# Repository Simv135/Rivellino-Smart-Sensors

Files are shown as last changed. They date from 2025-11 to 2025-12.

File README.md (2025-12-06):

# Rivellino Smart Sensors

## Introduzione

Il sistema **Rivellino Smart Sensors** è progettato per monitorare le condizioni ambientali all'interno del ***Rivellino degli Invalidi***, parte del **Museo Pietro Micca** di Torino.  
I sensori installati nei tre moduli principali **Tirante (A)**, **Galleria (B)** e **Polveriera (C)** raccolgono dati su:

- Temperatura e Umidità  
- Qualità dell’aria (CO e NO₂)  
- Vibrazioni
- Allagamento

Questi dati vengono trasmessi via seriale ad un Raspberry Pi e letti da un ricevitore scritto in Python, che li elabora e li salva automaticamente in file CSV.  
Il sistema garantisce un monitoraggio continuo e affidabile degli ambienti ipogei, contribuendo alla **tutela e alla conservazione del patrimonio storico**.

## I moduli
- [Modulo Ricevitore](#Il-ricevitore) per l'elaborazione dei dati
- [Modulo A](#Modulo-A) → tirante (Temperatura e Umidità, Aria, Vibrazioni)
- [Modulo B](#Modulo-B) → galleria (Batterie, Temperatura e Umidità, Aria, Allagamento)
- [Modulo C](#Modulo-C) → polveriera (Batterie, Temperatura e Umidità)

diagramma_funzionale

<br><br>

## I dati

| ID | Descrizione | Valore | Modulo  |
|---|---|---|---|
| a | Batteria | % | B |
| b | Batteria | % | C |
| c | Temperatura | °C | A |
| d | Temperatura | °C | B |
| e | Temperatura | °C | C |
| f | Umidità | % | A |
| g | Umidità | % | B |
| h | Umidità | % | C |
| i | Aria (CO) | ppm | A |
| j | Aria (NO2) | ppm | B |
| k | Vibrazioni | Hz | A |
| l | Vibrazioni | m/s² | A |
| m | Allagamento | 0 / 1 | B |

I dati verranno elaborati dal ricevitore e salvati all'interno dei files CSV.

<br><br>

## Posizionamento

Mappa_Rivellino

<br><br>

## Disegno Meccanico

| | |
|:---:|:---:|
| ModuloA | ModuloB |
| [ModuloA](disegno_meccanico/moduloA/Case_Tirante.stl) | [ModuloB e ModuloC](disegno_meccanico/moduloB/Case_Galleria.stl) |
| ModuloA_Condotto | Coperchio |
| [Condotto Aria (ModuloA)](disegno_meccanico/moduloA/Condotto_Aria.stl) | [Coperchio (ModuloA, ModuloB e Modulo C)](disegno_meccanico/moduloA/Coperchio.stl) |

<br><br>

## Il ricevitore

Assicurarsi di avere l'ultima versione di Python3 installata sul dispositivo (in questo caso sul Raspberry Pi 5).

Eseguire ```pip install pyserial``` nel terminale per installare la libreria pyserial.

Eseguire ```python3 main.py``` nel terminale, all'interno della cartella in cui si trova il programma ricevitore.

Il programma proverà a connettersi alla porta seriale. Quando la connessione sarà stabilita verrà mostrata la porta utilizzata e la velocità di comunicazione impostata.

Il programma riceverà dati periodicamente. Esempio di dati inviati da parte dei moduli:
- moduloA:    `c28f58j0.06k15.5l1.9i0.07`
- moduloB:    `a61d27g56m1`
- moduloC:    `b62e28h42`

I dati verranno salvati nella cartella DatiSensori nei seguenti files:

| File CSV | ID del dato |
|---|---|
| allagamento.csv | m |
| ariaCO.csv | i |
| ariaNO2.csv | j |
| batterie.csv | a, b |
| vibrazioni.csv | k, l |
| temperatura_umidita.csv | c, d, e, f, g, h |

Il file di configurazione `config.py` permette di modificare alcuni parametri relativi al programma di ricezione dei dati, tra cui:
- Selezionare la porta di comunicazione
- Selezionare la velocità di comunicazione (baud rate)
- Selezionare il percorso dei files CSV
- Rinominare i files CSV e di inserirne di nuovi
- Mappare nuovi sensori
- Modificare le colonne dei files CSV
- Scegliere se mostrare i dati ricevuti sul terminale
- Personalizzare i messaggi di log

Le informazioni di comunicazione ed eventuali errori saranno salvati all'interno di: `logfile.log`

## Librerie Arduino
Estrarre `libraries.zip` all'interno della cartella `C:\Users\%USERPROFILE%\Documents\Arduino\`, riavviare eventualmente Arduino IDE.

## Configurazione LoRa
- Lora Modulo A
  - `AT+ADDRESS=1`
  - `AT+NETWORKID=5`
  - `AT+IPR=9600`
- Lora Modulo B
  - `AT+ADDRESS=2`
  - `AT+NETWORKID=5`
  - `AT+IPR=9600`
- Lora Modulo C
  - `AT+ADDRESS=3`
  - `AT+NETWORKID=5`
  - `AT+IPR=9600`

## Modulo A

ModuloA

<br><br>

**Componenti**:
- Arduino Nano 33 BLE Sense Rev2
- Sensore Qualità Aria Mikroe3056
- Modulo LoRa RYLR498

Esempio di dati inviati:
`c28f58j0.06k15.5l1.9i0.07`

| ID | Descrizione | Valore |
|---|---|---|
| c | Temperatura | °C |
| f | Umidità | % |
| i | Aria (CO) | ppm |
| j | Aria (NO2) | ppm |
| k | Vibrazioni | Hz |
| l | Vibrazioni | m/s² |

<br><br>

## Modulo B

ModuloB

<br><br>

**Componenti**:
- Arduino Pro Mini
- Sensore Temperatura e Umidità DHT11
- Sensore Allagamento HW-038
- Modulo LoRa RYLR498
- Batterie AA Alcaline x5 (serie)

Esempio di dati inviati:
`a61d27g56m1`

| ID | Descrizione | Valore |
|---|---|---|
| a | Batteria | % |
| d | Temperatura | °C |
| g | Umidità | % |
| m | Allagamento | 0 / 1 |

<br><br>

## Modulo C

ModuloC

<br><br>

**Componenti**:
- Arduino Pro Mini
- Sensore Temperatura e Umidità DHT11
- Modulo LoRa RYLR498
- Batterie AA Alcaline x5 (serie)

Esempio di dati inviati:
`b62e28h42`

| ID | Descrizione | Valore |
|---|---|---|
| b | Batteria | % |
| e | Temperatura | °C |
| h | Umidità | % |

<br><br>

***ITS AEROSPAZIO PIEMONTE***

***CORSO EMBT02***

***Rivellino Smart Sensors***

<br><br>

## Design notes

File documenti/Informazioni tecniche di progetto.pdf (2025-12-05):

# Rivellino Smart Sensors

## Introduzione

Il sistema Rivellino Smart Sensors è progettato per monitorare le condizioni ambientali all'interno del Rivellino degli Invalidi, parte del Museo Pietro Micca di Torino.
I sensori installati nei tre moduli principali Tirante (A), Galleria (B) e Polveriera (C) raccolgono dati su:
- Temperatura e Umidità
- Qualità dell’aria (CO e NO₂)
- Vibrazioni
- Allagamento

Questi dati vengono trasmessi via seriale ad un Raspberry Pi e letti da un ricevitore scritto in Python, che li elabora e li salva automaticamente in file CSV.
Il sistema garantisce un monitoraggio continuo e affidabile degli ambienti ipogei, contribuendo alla tutela e alla conservazione del patrimonio storico.

## I moduli

- Modulo Ricevitore per l'elaborazione dei dati
- Modulo A → tirante (Temperatura e Umidità, Aria, Vibrazioni)
- Modulo B → galleria (Batterie, Temperatura e Umidità, Aria, Allagamento)
- Modulo C → polveriera (Batterie, Temperatura e Umidità)

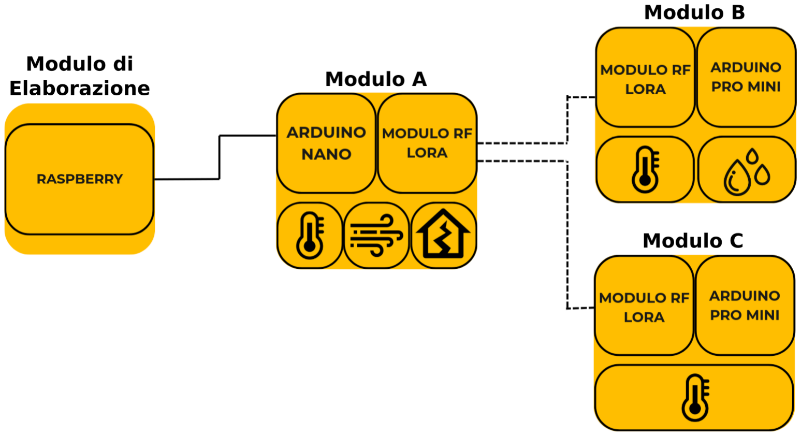
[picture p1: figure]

## I dati

ID | Descrizione | Valore | Modulo
a | Batteria | % | B
b | Batteria | % | C
c | Temperatura | °C | A
d | Temperatura | °C | B
e | Temperatura | °C | C
f | Umidità | % | A
g | Umidità | % | B
h | Umidità | % | C
i | Aria (CO) | ppm | A
j | Aria (NO2) | ppm | B
k | Vibrazioni | Hz | A
l | Vibrazioni | m/s² | A
m | Allagamento | 0 / 1 | B

I dati verranno elaborati dal ricevitore e salvati all'interno dei files CSV.

## Posizionamento

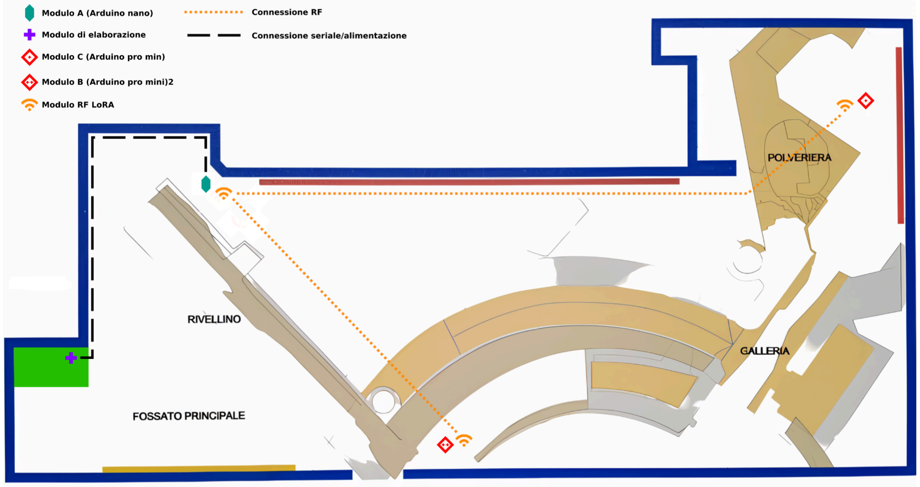
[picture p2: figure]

## Il ricevitore

Assicurarsi di avere l'ultima versione di Python3 installata sul dispositivo (in questo caso sul Raspberry Pi 5).

Eseguire pip install pyserial nel terminale per installare la libreria pyserial.

Eseguire python3 main.py nel terminale, all'interno della cartella in cui si trova il programma ricevitore.

Il programma proverà a connettersi alla porta seriale. Quando la connessione sarà stabilita verrà mostrata la porta utilizzata e la velocità di comunicazione impostata.

Il programma riceverà dati periodicamente. Esempio di dati inviati da parte dei moduli:

- moduloA: c28f58j0.06k15.5l1.9i0.07
- moduloB: a61d27g56m1
- moduloC: b62e28h42

I dati verranno salvati nella cartella “DatiSensori” nei seguenti files:

File CSV | ID del dato
allagamento.csv | m
ariaCO.csv | i
ariaNO2.csv | j
batterie.csv | a, b
vibrazioni.csv | k, l
temperatura_umidita.csv | c, d, e, f, g, h

Il file di configurazione config.py permette di modificare alcuni parametri relativi al programma di ricezione dei dati, tra cui:

- Selezionare la porta di comunicazione
- Selezionare la velocità di comunicazione (baud rate)
- Selezionare il percorso dei files CSV
- Rinominare i files CSV e di inserirne di nuovi

- Mappare nuovi sensori
- Modificare le colonne dei files CSV
- Scegliere se mostrare i dati ricevuti sul terminale
- Personalizzare i messaggi di log

Le informazioni di comunicazione ed eventuali errori saranno salvati all'interno di: logfile.log

## Librerie Arduino

Estrarre libraries.zip all'interno della cartella C:\Users\%USERPROFILE%\Documents\Arduino\, riavviare eventualmente Arduino IDE.

## Configurazione LoRa

- Lora Modulo A
- AT+ADDRESS=1
- AT+NETWORKID=5
- AT+IPR=9600
- Lora Modulo B
- AT+ADDRESS=2
- AT+NETWORKID=5
- AT+IPR=9600
- Lora Modulo C
- AT+ADDRESS=3
- AT+NETWORKID=5
- AT+IPR=9600

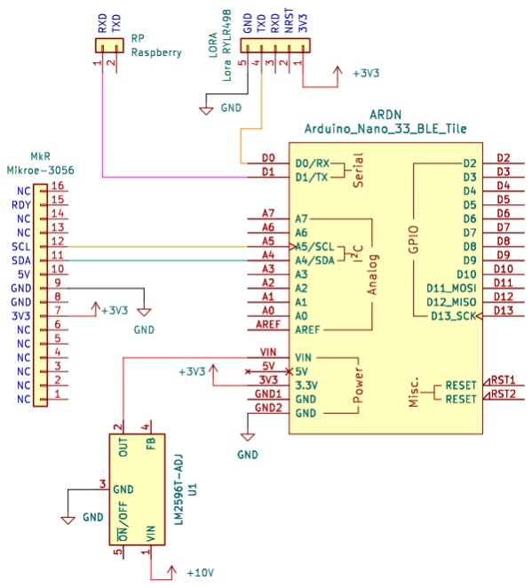
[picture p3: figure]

## Modulo A

Componenti:

- Arduino Nano 33 BLE Sense Rev2
- Sensore Qualità Aria Mikroe3056
- Modulo LoRa RYLR498

Esempio di dati inviati:
c28f58j0.06k15.5l1.9i0.07

ID | Descrizione | Valore
c | Temperatura | °C
f | Umidità | %
i | Aria (CO) | ppm
j | Aria (NO2) | ppm
k | Vibrazioni | Hz
l | Vibrazioni | m/s²

## Modulo B

Componenti:

- Arduino Pro Mini
- Sensore Temp. e Umidità DHT11
- Sensore Allagamento HW-038
- Modulo LoRa RYLR498
- Batterie AA Alcaline x5 (serie)

Esempio di dati inviati: a61d27g56m1

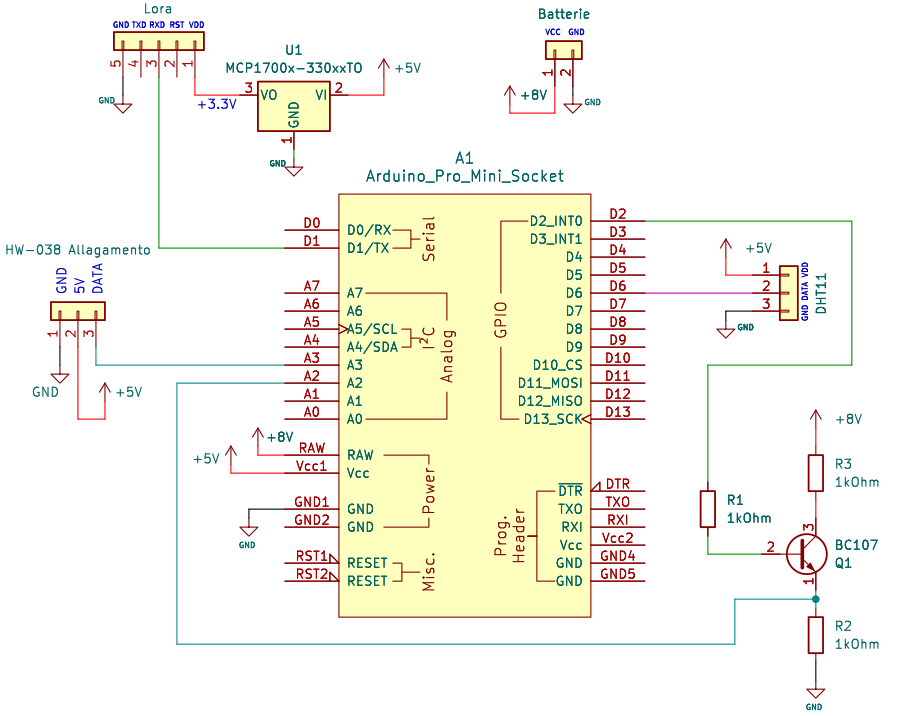
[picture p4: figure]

ID | Descrizione | Valore
a | Batteria | %
d | Temperatura | °C
g | Umidità | %
m | Allagamento | 0 / 1

## Modulo C

Componenti:

- Arduino Pro Mini
- Sensore Temp. e Umidità DHT11
- Modulo LoRa RYLR498
- Batterie AA Alcaline x5 (serie)

Esempio di dati inviati: b62e28h42

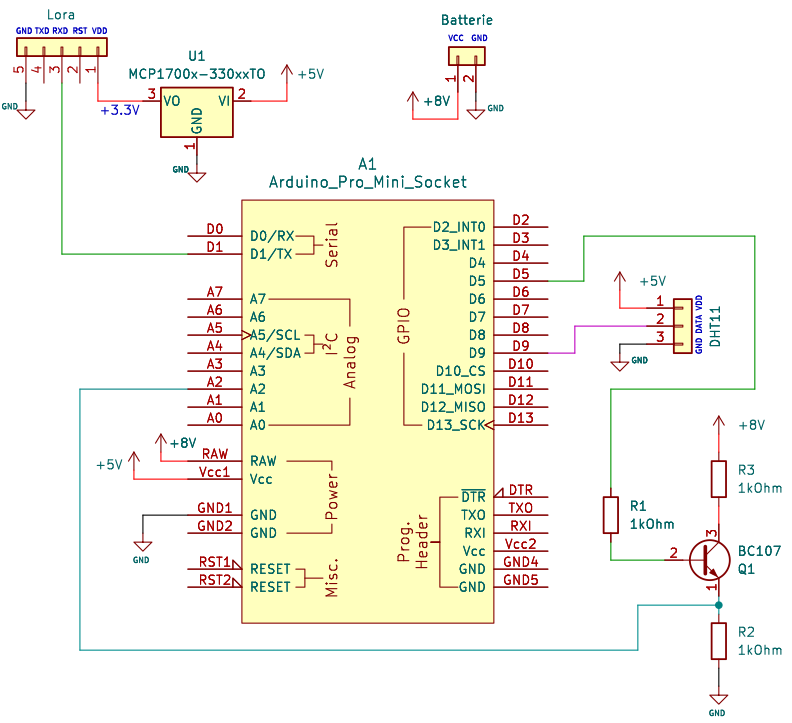
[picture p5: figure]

ID | Descrizione | Valore
b | Batteria | %
e | Temperatura | °C
h | Umidità | %

ITS AEROSPAZIO PIEMONTE
CORSO EMBT02
Rivellino Smart Sensors | https://github.com/Simv135/Rivellino-Smart-Sensors

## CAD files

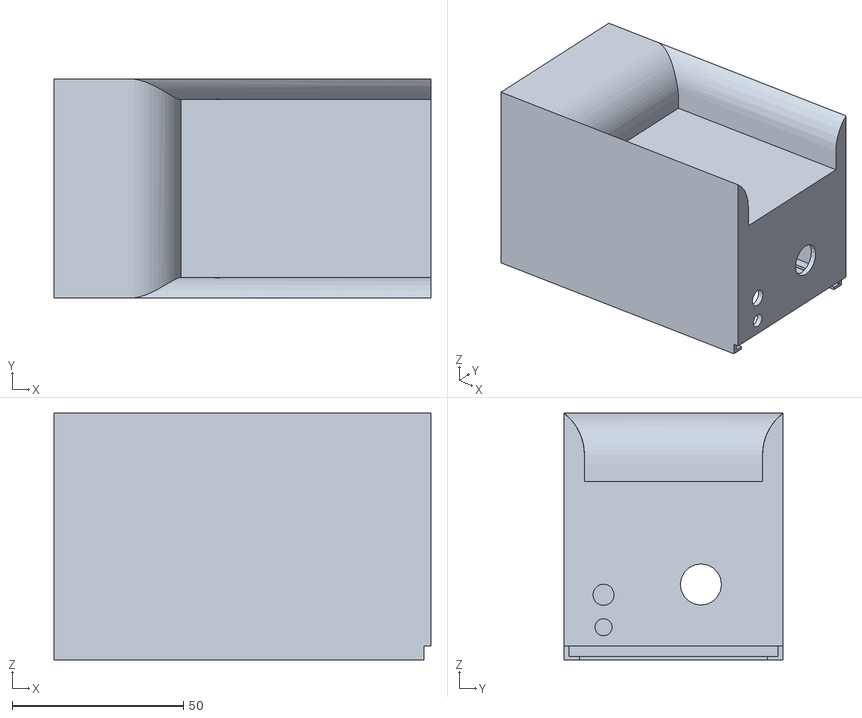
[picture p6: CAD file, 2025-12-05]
disegno_meccanico/moduloA/Case_Tirante.stl
110.0 x 64.0 x 72.0

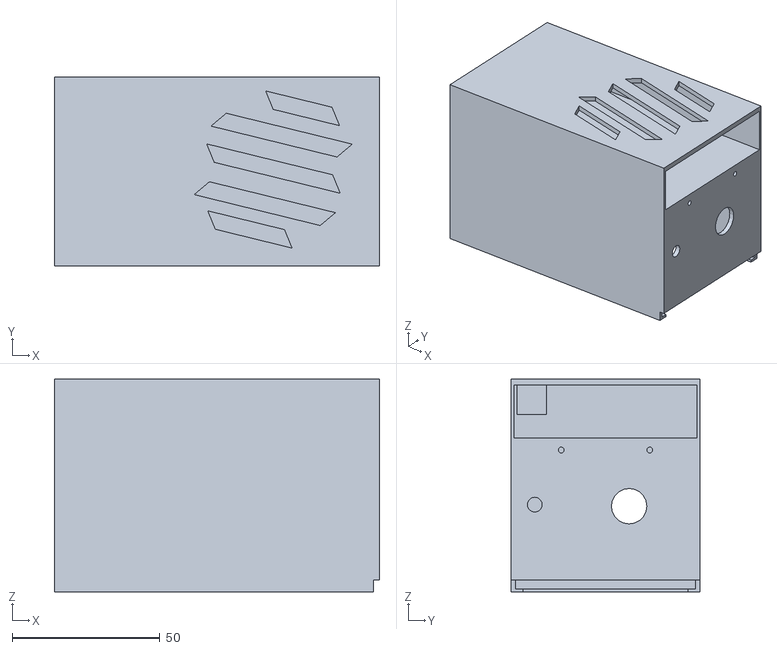
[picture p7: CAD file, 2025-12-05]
disegno_meccanico/moduloB/Case_Galleria.stl
110.0 x 64.0 x 72.0

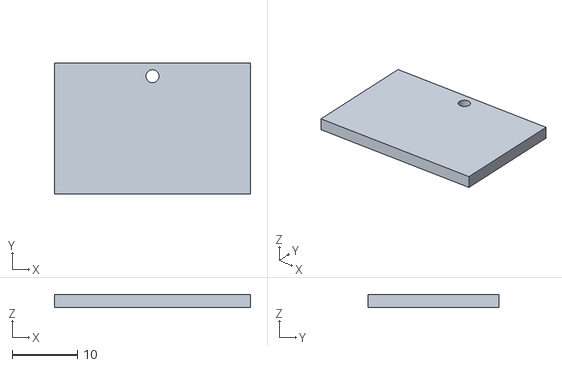
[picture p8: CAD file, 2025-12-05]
disegno_meccanico/moduloC/Vano_Batteria.stl
30.0 x 20.0 x 2.00

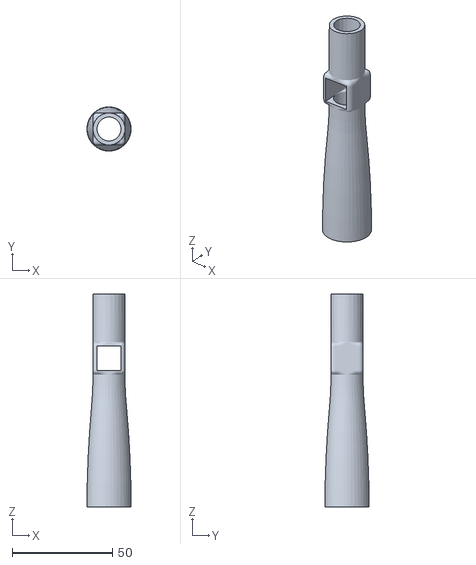
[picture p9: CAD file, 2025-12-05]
disegno_meccanico/moduloA/Condotto_Aria.stl
22.0 x 22.0 x 106.0

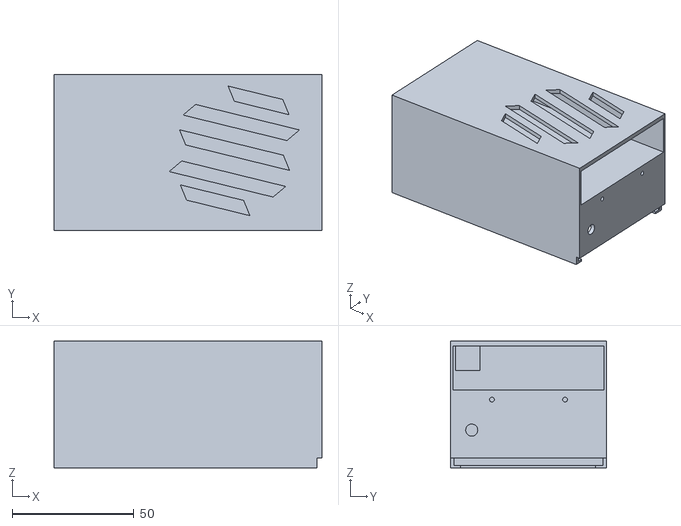
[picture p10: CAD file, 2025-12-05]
disegno_meccanico/moduloC/Case_Polveriera.stl
110.0 x 64.0 x 52.0

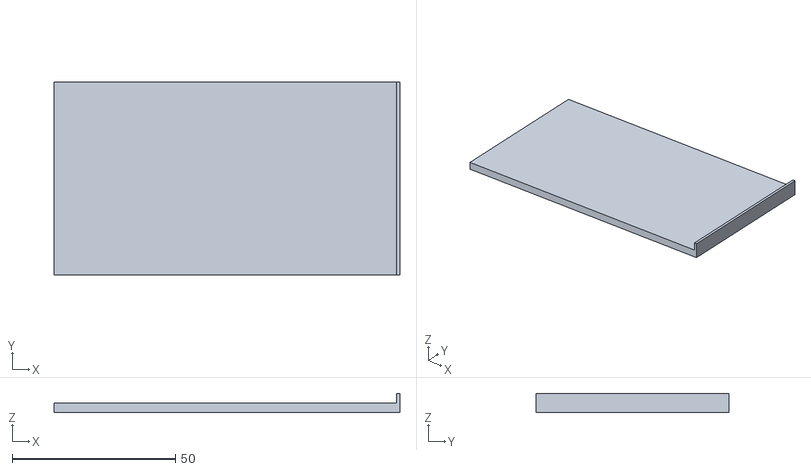
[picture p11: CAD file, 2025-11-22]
disegno_meccanico/moduloA/Coperchio.stl
106.0 x 59.0 x 5.90

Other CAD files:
disegno_meccanico/moduloA/Case_Tirante.prt
disegno_meccanico/moduloA/Condotto_Aria.prt
disegno_meccanico/moduloA/Coperchio.prt
disegno_meccanico/moduloB/Case_Galleria.prt
disegno_meccanico/moduloB/Coperchio.prt
disegno_meccanico/moduloB/Vano_Batteria.prt
disegno_meccanico/moduloC/Case_Polveriera.prt
disegno_meccanico/moduloC/Coperchio.prt
disegno_meccanico/moduloC/Vano_Batteria.prt

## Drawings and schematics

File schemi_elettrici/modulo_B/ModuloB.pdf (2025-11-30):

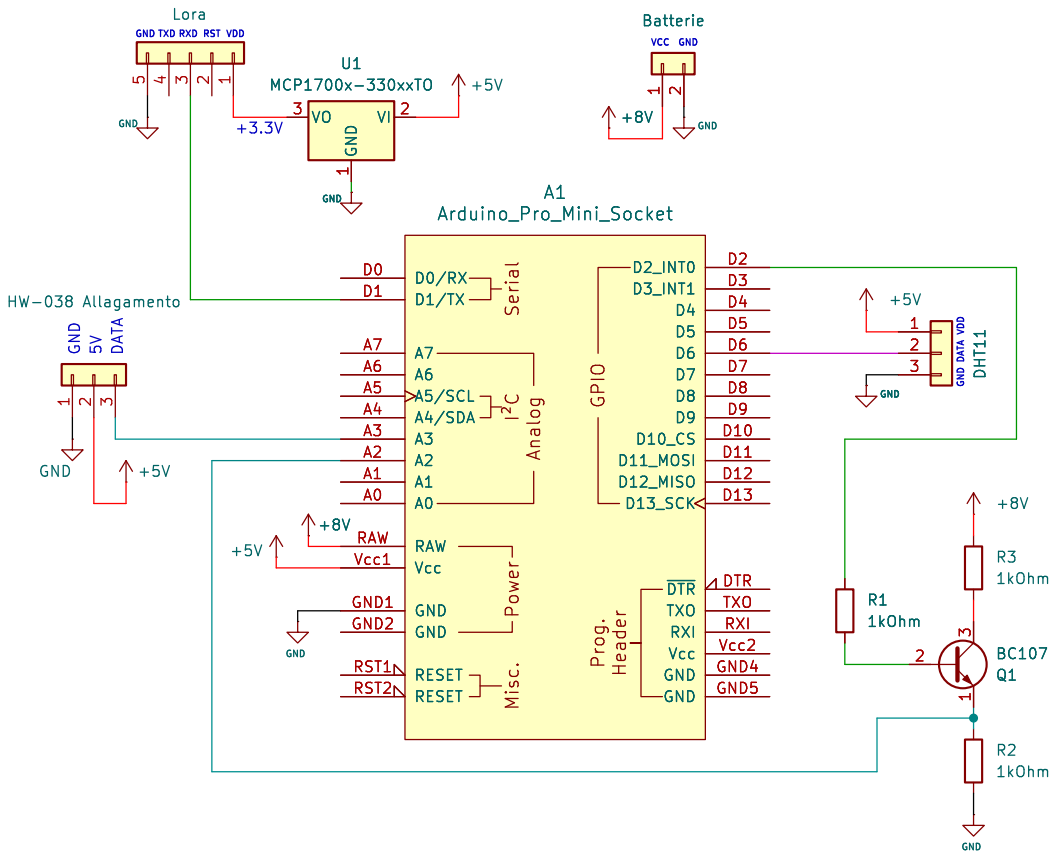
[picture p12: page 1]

3 1 A1 Arduino_Pro_Mini_Socket D0/RX D0 D1/TX D1 A7 A7 A6 A6 A5/SCL A5 A4/SDA A4 A3 A3 A2 A2 A1 A1 A0 A0 RAW RAW

3 HW-038 Allagamento Serial þÿI²C Power Misc. AnalogGPIO Prog. Header D0/RX D0 D1/TX D1 A7 A7 A6 A6 A5/SCL A5 A4/SDA A4 A3 A3 A2 A2 A1 A1 A0 A0 RAW RAW

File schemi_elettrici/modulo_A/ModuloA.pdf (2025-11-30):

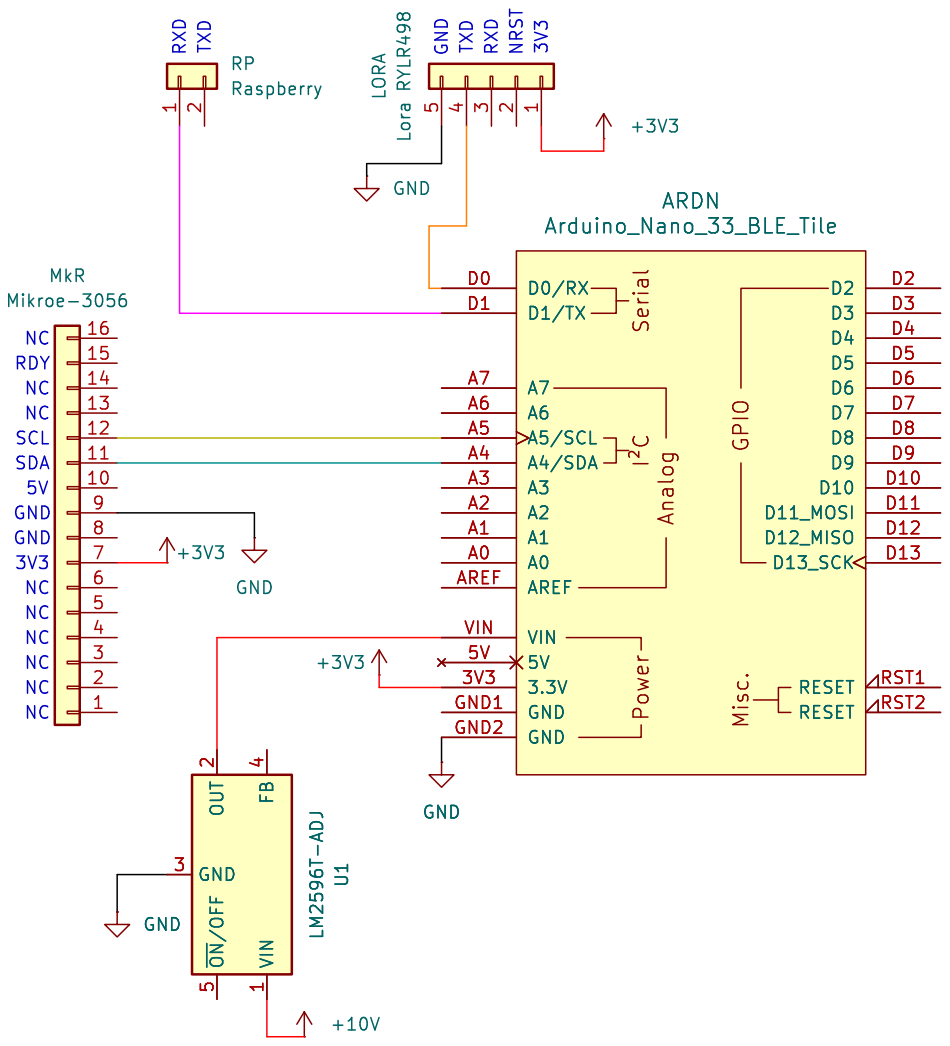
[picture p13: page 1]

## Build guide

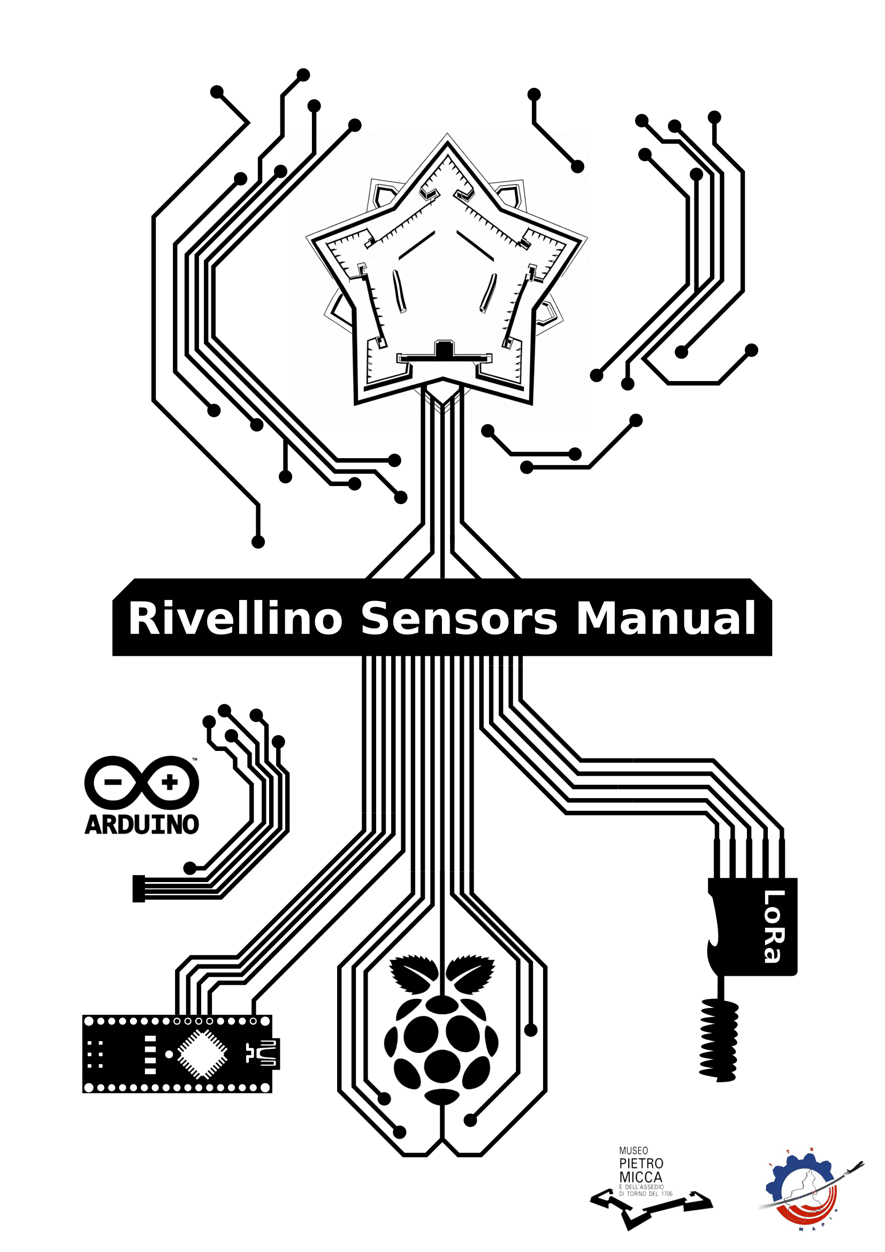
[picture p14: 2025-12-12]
documenti/documenti_editabili_e_immagini/riivellino_manual_first_page_Gabriele_Barletta_EMBT02.png

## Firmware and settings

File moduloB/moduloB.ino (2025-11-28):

//Estrarre "libraries.zip" all'interno della cartella "C:\Users\%USERPROFILE%\Documents\Arduino\", riavviare eventualmente Arduino IDE
//impostare usb to ttl con vdd a 5V
//collegare VDD e GND
//collegare tx(usb to ttl) con rx(Arduino) ed rx(usb to ttl) con tx(Arduino)
//premere il pulsante di reset subito dopo la compilazione del codice per caricare il codice sul Pro Mini e non collegare il pin di reset
//Per info: https://github.com/Simv135/Rivellino-Smart-Sensors

// --- LIBRERIE ---
#include <Wire.h>
#include "DHT.h"
#include <avr/sleep.h>
#include <avr/power.h>
#include <avr/wdt.h>

// --- CONFIGURAZIONI ---
#define WDT_INTERVAL          8     // Ogni ciclo WDT è 8s
#define TEMP_HUM_CYCLES       4     // Leggi ogni 32s
#define WATER_CYCLES          1     // Leggi ogni 8s
#define WATER_THRESHOLD       10    // Soglia allagamento

// --- PIN ---
#define DHT11_DATA_PIN        6
#define HW038_DATA_PIN        A3
#define BATTERY_READ_EN       2
#define BATTERY_READ_PIN      A2
#define LED_BATTERY           11  //da completare il circuito con il LED nel circuito

DHT dht11(DHT11_DATA_PIN, DHT11);

// --- VARIABILI SENSORI ---
float temp, hum;
unsigned short voltage;
byte battery;
bool all;

// --- VARIABILI TIMER ---
volatile byte temp_hum_counter = 0;
volatile byte water_counter = 0;
volatile bool time_to_read_temp_hum = false;
volatile bool time_to_read_water = false;

// --- SETUP ---
void setup() {
  Serial.begin(9600);
  while (!Serial);

  pinMode(BATTERY_READ_EN,OUTPUT);

  dht11.begin();

  setupWatchdog();

  powerStateLed();  //visualizza stato della batteria partendo dal LED
  //Implementare un pulsante di reset per visualizzare lo stato della batteria manualmente
}

// --- LOOP PRINCIPALE ---
void loop() {
  sleepUntilNextReading();

  if (time_to_read_temp_hum) {
    readTempHum();
    readBattery();
    sendData(
      "d" + String(temp) + 
      "g" + String(hum) + 
      "m" + String(all) + 
      "a" + String(battery)
    );
    time_to_read_temp_hum = false;
  }

  if (time_to_read_water) {
    readWater();
    if (all=1){
      sendData("m" + String(all));
    }
    time_to_read_water = false;
  }
}

// --- INVIO DATI ---
void sendData(String data) {
  Serial.println("AT+MODE=0"); //sleep off
  delay(500);

  Serial.print("AT+SEND=1,");
  Serial.print(data.length());
  Serial.print(",");
  Serial.println(data);

  delay(1000);
  Serial.println("AT+MODE=1"); //sleep on
}

// --- LETTURA TEMPERATURA / UMIDITÀ ---
void readTempHum() {
  temp = dht11.readTemperature();
  hum = dht11.readHumidity();
}

// --- LETTURA ALLAGAMENTO ---
void readWater() {
  int count = 0;
  for (byte i = 0; i < 5; i++) {
    count += (analogRead(HW038_DATA_PIN) >= WATER_THRESHOLD);
    delay(5);
  }

  all = (count >= 3);
}

// --- LETTURA BATTERIA ---
void readBattery() {
  digitalWrite(BATTERY_READ_EN,HIGH);
  delay(1000);
  voltage = analogRead(BATTERY_READ_PIN);
  digitalWrite(BATTERY_READ_EN,LOW);

  //da calcolare meglio le soglie in base al partitore di tensione nel circuito
  //                   ^
  //                   |
  if      (voltage < 4600) battery = 0;
  else if (voltage < 4850) battery = 20;
  else if (voltage < 4950) battery = 40;
  else if (voltage < 5000) battery = 60;
  else if (voltage < 5025) battery = 80;
  else                     battery = 100;
}

// --- LED BATTERIA ---
//Indicatore LED per lo stato della batteria
void powerStateLed(){ 
  readBattery();
  if (battery==0){
    digitalWrite(LED_BATTERY, HIGH);
    delay(500);
    digitalWrite(LED_BATTERY, LOW);
  }else if (battery<=20){
    digitalWrite(LED_BATTERY, HIGH);
    delay(500);
    digitalWrite(LED_BATTERY, LOW);
    delay(500);
    digitalWrite(LED_BATTERY, HIGH);
    delay(500);
    digitalWrite(LED_BATTERY, LOW);
  }else if (battery<=40){
    digitalWrite(LED_BATTERY, HIGH);
    delay(1000);
    digitalWrite(LED_BATTERY, LOW);
  }else if (battery<=60){
    digitalWrite(LED_BATTERY, HIGH);
    delay(1000);
    digitalWrite(LED_BATTERY, LOW);
    delay(1000);
    digitalWrite(LED_BATTERY, HIGH);
    delay(1000);
    digitalWrite(LED_BATTERY, LOW);
  }else if (battery<=80){
    digitalWrite(LED_BATTERY, HIGH);
    delay(2000);
    digitalWrite(LED_BATTERY, LOW);
  }else if (battery<=100){
    digitalWrite(LED_BATTERY, HIGH);
    delay(2000);
    digitalWrite(LED_BATTERY, LOW);
    delay(2000);
    digitalWrite(LED_BATTERY, HIGH);
    delay(2000);
    digitalWrite(LED_BATTERY, LOW);
  }
}

// --- WATCHDOG ---
void setupWatchdog() {
  cli();
  wdt_reset();
  MCUSR &= ~(1 << WDRF);
  WDTCSR |= (1 << WDCE) | (1 << WDE);
  WDTCSR = (1 << WDIE) | (1 << WDP3) | (0 << WDP2) | (0 << WDP1) | (1 << WDP0); // 8s
  sei();
}

ISR(WDT_vect) {
  temp_hum_counter++;
  water_counter++;

  if (water_counter >= WATER_CYCLES) {
    time_to_read_water = true;
    water_counter = 0;
  }

  if (temp_hum_counter >= TEMP_HUM_CYCLES) {
    time_to_read_temp_hum = true;
    temp_hum_counter = 0;
  }
}

// --- SLEEP ---
void sleepUntilNextReading() {
  ADCSRA &= ~(1 << ADEN);
  set_sleep_mode(SLEEP_MODE_PWR_DOWN);
  do {
    sleep_enable();
    sleep_mode();
    sleep_disable();
  } while (!time_to_read_temp_hum && !time_to_read_water);
  ADCSRA |= (1 << ADEN);
}
  

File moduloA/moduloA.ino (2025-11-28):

//Estrarre "libraries.zip" all'interno della cartella "C:\Users\%USERPROFILE%\Documents\Arduino\", riavviare eventualmente Arduino IDE
//Per info: https://github.com/Simv135/Rivellino-Smart-Sensors

// --- LIBRERIE ---
#include "Arduino_BMI270_BMM150.h"
#include <Arduino_HS300x.h>
#include <math.h>  // Per fabs() e isnan()

// Librerie sensore aria
#include <Wire.h>
#include <Adafruit_ADS1X15.h>

// Creazione dell'istanza dell'ADS1115
Adafruit_ADS1X15 ads;

// Costanti di configurazione
#define VIBRATION_THRESHOLD 0.03            // Soglia variazione accelerazione per stampare
#define VIBRATION_MIN_INTERVAL 50           // Minimo tempo tra rilevazioni valide (ms)
#define ENV_INTERVAL 5000                   // Intervallo lettura temperatura/umidità e aria (ms)

// Variabili aria
float R0_CO = 10.0;   // Resistenze in aria pulita
float R0_NO2 = 20.0;  
int16_t co_raw; // tensioni dai canali ADC
int16_t no2_raw;
float co_voltage; // valori raw in tensione (V)
float no2_voltage;
float R_s_CO; // resistenza del sensore (R_s)
float R_s_NO2;
float ppm_CO; // concentrazioni in ppm
float ppm_NO2;

// Variabili vibrazione
float x, y, z;
float vibration = 0.0;
float lastVibration = 0.0;
float lastPrintedVibration = 0.0;
float lastPrintedFrequency = 0.0;
bool firstRead = true;

// Variabili frequenza
unsigned long lastTime = 0;
unsigned long currentTime = 0;
unsigned long deltaTime = 0;
float frequencyVibration = 0.0;

// Variabili messaggi
String rawData, message;
int firstComma, secondComma, thirdComma;

// Timer temperatura/umidità
unsigned long lastEnvRead = 0;
unsigned long currentMillis = 0;

void setup() {
  Serial1.begin(9600);
  while (!Serial1);
  Serial.begin(9600);
  while (!Serial);

  ads.begin();

  if (!IMU.begin()) {
    Serial1.println("[A] Errore inizializzazione IMU!");
    Serial.println("[A] Errore inizializzazione IMU!");
    while (1);
  }

  if (!HS300x.begin()) {
    Serial1.println("[A] Errore inizializzazione sensore HS300x!");
    Serial.println("[A] Errore inizializzazione sensore HS300x!");
    while (1);
  }
}

void loop() {
  currentMillis = millis();

  if (readAccelerometer()) {
    // Filtro per stampare solo se:
    // - la vibrazione è cambiata significativamente
    // - la frequenza è cambiata abbastanza da evitare ripetizioni inutili
    if (fabs(vibration - lastPrintedVibration) >= VIBRATION_THRESHOLD &&
        fabs(frequencyVibration - lastPrintedFrequency) >= 0.5 &&
        deltaTime != VIBRATION_MIN_INTERVAL &&
        frequencyVibration > 0.0 && frequencyVibration < 100.0)
    {
      printVibrationData();
      lastPrintedVibration = vibration;
      lastPrintedFrequency = frequencyVibration;
    }
  }

  if (currentMillis - lastEnvRead >= ENV_INTERVAL) {
    lastEnvRead = currentMillis;
    printAirData();
    printTempHumData();
  }

  receiveData();
}

void receiveData() {

  if (Serial1.available()) {
    rawData = Serial1.readStringUntil('\n');  // Legge fino a newline

    if (rawData.startsWith("+RCV=")) {
      firstComma = rawData.indexOf(',');
      secondComma = rawData.indexOf(',', firstComma + 1);
      thirdComma = rawData.indexOf(',', secondComma + 1);

      if (firstComma > 0 && secondComma > 0 && thirdComma > 0) {
        message = rawData.substring(secondComma + 1, thirdComma);
        Serial1.println(message);
        Serial.println(message);
      }
    }
  }
}

// Funzione per lettura accelerometro e calcolo frequenza
bool readAccelerometer() {
  if (IMU.accelerationAvailable()) {
    IMU.readAcceleration(x, y, z);
    vibration = sqrt(x * x + y * y + z * z);  // Magnitudo accelerazione

    if (firstRead || fabs(vibration - lastVibration) >= VIBRATION_THRESHOLD) {
      currentTime = millis();
      deltaTime = currentTime - lastTime;

      if (!firstRead && deltaTime >= VIBRATION_MIN_INTERVAL) {
        frequencyVibration = 1000.0 / deltaTime;
      }

      lastTime = currentTime;
      lastVibration = vibration;
      firstRead = false;
    }
  }

  return (!isnan(vibration) && frequencyVibration > 0.0 && frequencyVibration < 100.0);
}

void readAirQuality(){
  co_raw = ads.readADC_SingleEnded(0);
  no2_raw = ads.readADC_SingleEnded(1);
  
  // Conversione dei valori raw in tensione (V)
  co_voltage = co_raw * 6.144 / 32768.0;
  no2_voltage = no2_raw * 6.144 / 32768.0;
  
  // Calcolo della resistenza del sensore (R_s)
  R_s_CO = (5.0 - co_voltage) / co_voltage * R0_CO;
  R_s_NO2 = (5.0 - no2_voltage) / no2_voltage * R0_NO2;
  
  // Calcolo delle concentrazioni in ppm usando curve empiriche dal datasheet
  ppm_CO = pow((R_s_CO / R0_CO), -1.179) * 4.385;   // Formula per CO
  ppm_NO2 = pow((R_s_NO2 / R0_NO2), 1.007) * 6.855; // Formula per NO2
}

// Stampa dati aria
void printAirData() {
  readAirQuality();
  Serial.print("i");  // Aria CO
  Serial.print(ppm_CO);
  Serial.print("j");  // Aria NO2
  Serial.println(ppm_NO2);
}

// Stampa dati vibrazione
void printVibrationData() {
  Serial.print("k");  // Frequenza (Hz)
  Serial.print(frequencyVibration, 2);
  Serial.print("l");  // Intensità vibrazione (m/s²)
  Serial.println(vibration, 2);
}

// Stampa temperatura e umidità
void printTempHumData() {
  Serial.print("c");  // Temperatura
  Serial.print(HS300x.readTemperature());
  Serial.print("f");  // Umidità
  Serial.println(HS300x.readHumidity());
}

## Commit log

2025-05-19 Update moduloB.ino
    Correzione dell'errore migliorata
    [moduloB.ino]
2025-05-19 Update moduloC.ino
    correzione gestione errore batterie
    [moduloC.ino]
2025-11-28 Librerie Arduino (estrarre la zip e inserire le librerie in Documenti\Arduino\libraries\)
2025-12-05 Add new file 'da el' with initial content
